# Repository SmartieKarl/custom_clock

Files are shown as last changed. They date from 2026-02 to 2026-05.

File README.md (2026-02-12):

# Custom Clock

This is an ESP32 based alarm clock with RFID functionality. The idea behind
this is that in order to turn off your alarm in the morning, you have to
physically get out of bed, grab your NFC card, and tap it on the reciever to
turn your alarm off. At that point you'll be more awake and have less of a
reason to go back to bed.

--------------------------------------------------------------------------

**[Please see LICENSE file for complete terms and conditions.](./LICENSE)**

--------------------------------------------------------------------------

# Setup

## Hardware

### Boards
- **Microcontroller:** ESP-WROOM-32 Dev Module ([Amazon](https://www.amazon.com/YEJMKJ-ESP-WROOM-32-Development-Dual-Mode-Microcontroller/dp/B0CDRKX814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)) ([AliExpress](https://www.aliexpress.us/item/3256809488479021.html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))
- **Display:** ST7789 240×320 SPI TFT ([Amazon](https://www.amazon.com/XIITIA-Display-Screen-240%C3%97320-Arduino/dp/B0D5HCDNY5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)) ([AliExpress](https://www.aliexpress.us/item/3256806903354055.html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))
- **RTC:** DS3231 ([Amazon](https://www.amazon.com/CANADUINO%C2%AE-DS3231-Module-Interface-Battery/dp/B07BCPRH6F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)) ([AliExpress](https://www.aliexpress.us/item/3256806957282138.html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))
- **Audio:** DFPlayer Mini ([Amazon](https://www.amazon.com/DFPlayer-A-Mini-MP3-Player/dp/B089D5NLW1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)) ([AliExpress](https://www.aliexpress.us/item/3256808368233947.html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))
- **NFC Functions:** RFID-RC522 ([Amazon](https://www.amazon.com/HiLetgo-RFID-Kit-Arduino-Raspberry/dp/B01CSTW0IA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)) ([AliExpress](https://www.aliexpress.us/item/3256806642614131.html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))

### Misc hardware
- a 2" speaker with two jumper wires. I used [this one](https://www.aliexpress.us/item/3256809273226082.html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,scm-url:1007.40050.354490.0,pvid:ea5149e1-a9d5-4bd2-9c6d-d897df53609c,tpp_buckets:668%232846%238109%231935&pdp_ext_f=%7B%22order%22%3A%22272%22%2C%22eval%22%3A%221%22%2C%22sceneId%22%3A%2230050%22%2C%22fromPage%22%3A%22recommend%22%7D&pdp_npi=6%40dis%21USD%2111.22%210.99%21%21%2177.01%216.78%21%402101df0e17709188654595016e0e1b%2112000049170771831%21rec%21US%21%21ABXZ%211%210%21n_tag%3A-29910%3Bd%3Af98f678%3Bm03_new_user%3A-29895%3BpisId%3A5000000197847434&utparam-url=scene%3ApcDetailTopMoreOtherSeller%7Cquery_from%3A%7Cx_object_id%3A1005009459540834%7C_p_origin_prod%3A), they come in sets of 2.
- a 1x2 header (for speaker) [here](https://www.aliexpress.us/item/3256803424019097.html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)
- 4 tactile buttons (like [these]())
- a 1x8 header (Optional, but recommended for RFID scanner range to be adequate) [here](https://www.aliexpress.us/item/3256803424019097.html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)
- 14-pin ribbon cable [here](https://www.aliexpress.us/item/3256805224133202.html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) 
- 2 2x7 IDC connectors [here](https://www.digikey.com/en/products/detail/cw-industries/CWR-130-14-0000/9899)
- a 2x7 dip socket (optional, but recommended if you want a way to disconnect the boards) [here](https://www.newark.com/multicomp-pro/spc15496/dip-socket-14-position-through/dp/82K7787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|pcrid||plid||kword||match|e|slid||product|82K7787|pgrid|1231453304461926|ptaid|pla-4580565455222458|&msclkid=5e18dbcbb6c91ab8dd9ab2458683c106)
- a microsd card for DFPlayer (max 32gb)
- a photoresistor
- a 1kΩ resistor, 2.2kΩ resistor, and 4.7kΩ resistor
- a 10μF capacitor and a 0.1μF capacitor
- a usb-c cable (only needed if you want to use electricity)

**Make sure all hardware you get matches the hardware on the boards in the photos at the bottom of this file**

## Pin Connections

### ST7789 Display
| TFT Pin | ESP32 Pin |
|---|---|
| CS | GPIO15 |
| RST | GPIO4 |
| DC | GPIO2 |
| MOSI | GPIO23 |
| SCLK | GPIO18 |
| LED | GPIO26 |

### DS3231 RTC (I²C)
| RTC Pin | ESP32 Pin |
|---|---|
| SDA | GPIO21 |
| SCL | GPIO22 |

### DFPlayer Mini (UART)
| DFPlayer | ESP32 Pin |
|---|---|
| TX | GPIO16 |
| RX | GPIO17 |

### RFID-RC522 (SPI)
| RFID Pin | ESP32 Pin |
|---|---|
| SDA/SS | GPIO5 |
| SCK | GPIO18 |
| MOSI | GPIO23 |
| MISO | GPIO19 |
| GND | GND |
| RST | GPIO25 |
| 3.3V | 3.3V |

## Other wiring

**Buttons**
There are four simple tactile buttons in use, they all use ESP32's
internal pull-up resistors:
- Button 1 (screen top left): GPIO14 -> button1 -> GND 
- Button 2 (screen top right): GPIO27 -> button2 -> GND
- Button 3 (screen bottom left): GPIO33 -> button3 -> GND
- Button 4 (screen bottom right): GPIO32 -> button4 -> GND

**DFPlayer mini voltage divider**
- So the DFPlayer's TX pin doesn't send 5v signals back to GPIO16 (bad)
- TX -> 1kΩ resistor --> GPIO16
                      |
                      -> 2.2kΩ resistor -> GND

**Photoresistor Circuit:**
- For auto-brightness functions
- 3.3v -> photoresistor -> GPIO34
                        |
                        -> 4.7kΩ resistor -> GND

### Power Supply
- **ESP32 Module:** 5v DC (regulated to 3.3v on-board)
- **TFT Display:** 3.3V (from ESP32)
- **DS3231 RTC:** 3.3V  (from ESP32)
- **DFPlayer Mini:** 5V (from ESP32)
- **RFID-RC522:** 3.3v (from ESP32)

## Software
Software is designed to work with **PlatformIO IDE** on **VSCode**.
Make sure they're installed for this to work correctly!

# Assembly

## Materials
You will need:
- All listed hardware above
- Access to a 3d printer and PCB mill (there are online services)
- Soldering iron
- 2 9mm long 5mm screws
- 2 5mm nuts for screws

## Printing & Milling
- Included in this repo is a [clock_parts](./clock_parts) folder. It contains the
    - gerber files (Already formatted for PCB milling)
    - stl files (for 3d printing of the clock shell)

- 3d print both shell pieces and 2 copies of the board spacer piece. The display piece **must** be printed clear for the
photoresistor to do it's thing.

- Mill the boards (must be electroplated and double-sided).

- Solder everything to boards (like pictures below)

- Place nuts in the shell (in the suspiciously nut-shaped divots) You might need to use pliers to press them in there.
If you're desperate, you can get them hot with a soldering iron to melt them in.

- Slide main board into the main shell (so the usb port is lined up with the back)

- Push display board into the front display piece, lining up the photoresistor with the rectangle cut out on the inside.

- plug the speaker into the main board, and the display board into the main board.

- Close up the shell and screw the screws in.

- Assembled!

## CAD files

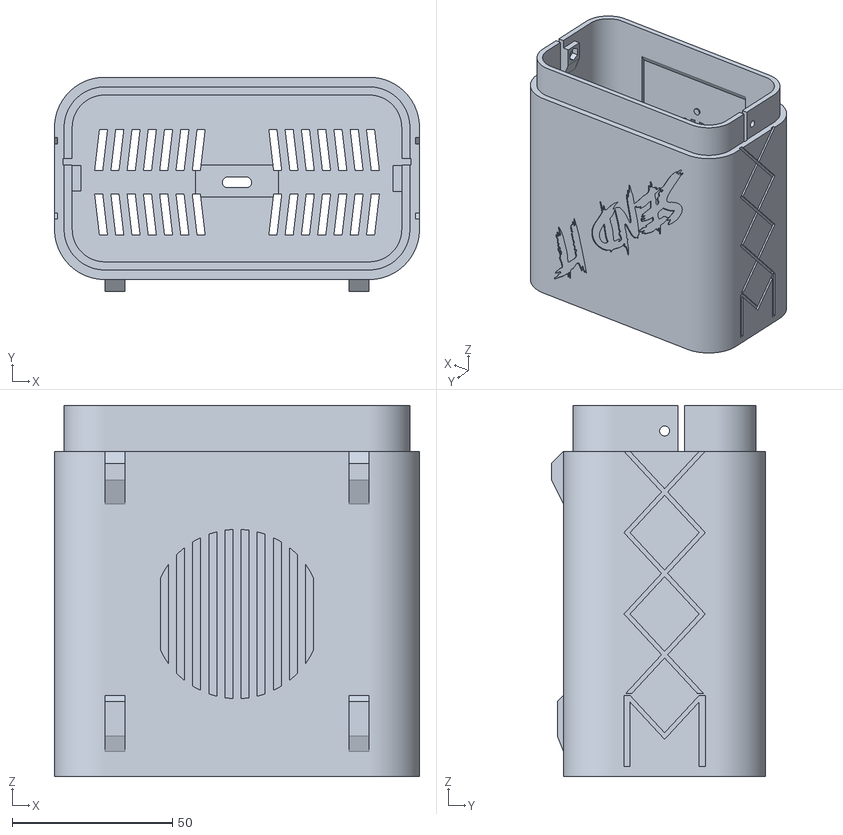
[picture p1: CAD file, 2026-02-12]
clock_parts/stl/clock_main_shell.stl
113.9 x 67.0 x 116.0

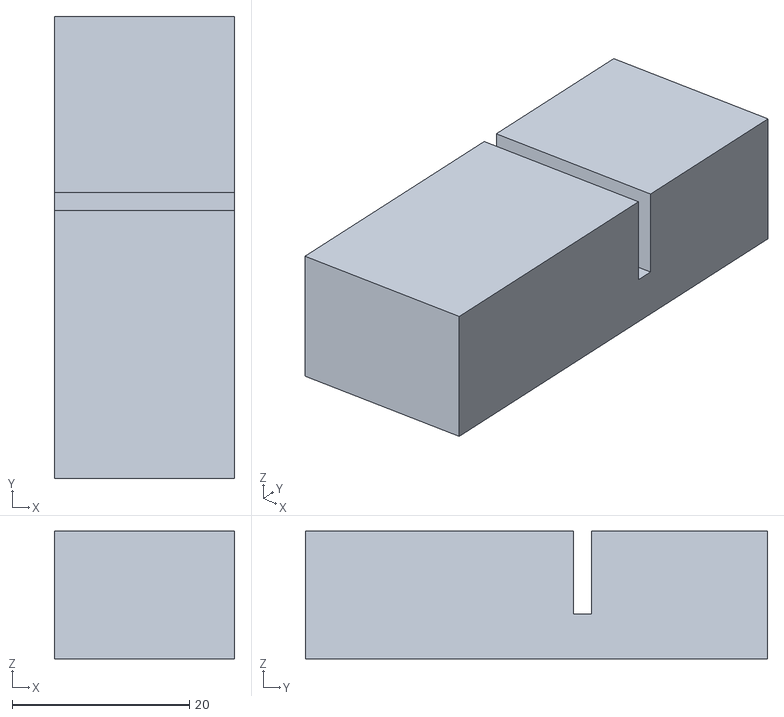
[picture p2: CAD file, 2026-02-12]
clock_parts/stl/clock_board_spacer.stl
20.3 x 52.1 x 14.4

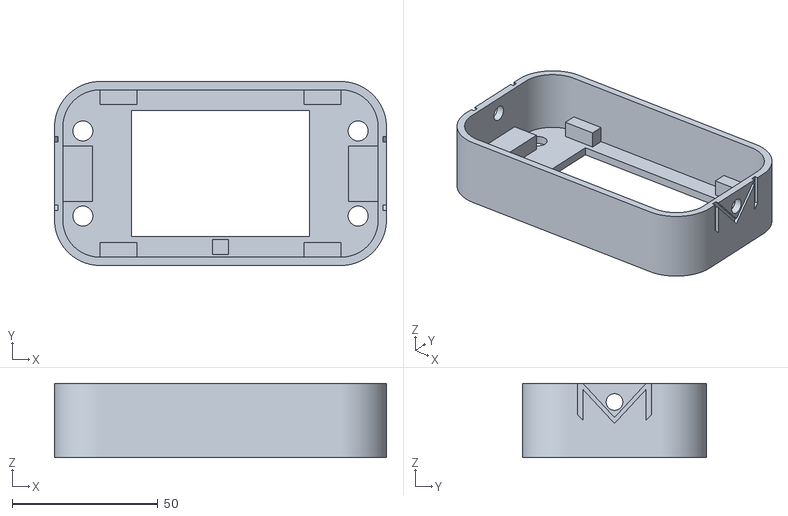
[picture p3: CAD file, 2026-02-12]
clock_parts/stl/clock_shell_front.stl
113.9 x 63.1 x 25.4

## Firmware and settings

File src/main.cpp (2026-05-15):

#include "AlarmSystem.h"
#include "AppController.h"
#include "BrightnessController.h"
#include "Buttons.h"
#include "CommandInterface.h"
#include "Config.h"
#include "Log.h"
#include "NetworkManager.h"
#include "RFIDHandler.h"
#include "Timekeeper.h"
#include "UI.h"
#include <DFRobotDFPlayerMini.h> // DFPlayer Mini core library
#include <HardwareSerial.h>      // Serial comms for DFPlayer Mini
#include <MFRC522.h>             // RFID core library
#include <RTClib.h>              // DS3231 RTC core library
#include <TFT_eSPI.h>            // ST7789 TFT core library
#include <esp_task_wdt.h>        // For freeRTOS task implementation

//==========
// TODO: Change singletons into universal objects to remove the need for object injection
//==========
// Hardware objects
DFRobotDFPlayerMini player;
HardwareSerial mySoftwareSerial(1); // UART1 for ESP32 (DFPlayer)
MFRC522 rfid(Pins::RFID_CS_PIN, Pins::RFID_RST_PIN);
RTC_DS3231 rtc;
TFT_eSPI tft = TFT_eSPI();

// Logic objects
Buttons btn(Pins::BUTTON_1_PIN, Pins::BUTTON_2_PIN, Pins::BUTTON_3_PIN, Pins::BUTTON_4_PIN); // TODO: add default pins into constructor
BrightnessController brightness;                                     // uses default pins from Config.h
Timekeeper timekeeper(rtc);
Log LOG(timekeeper);
NetworkManager networkManager(rtc);
RFIDHandler rfidHandler(rfid);
AlarmSystem alarmSystem(rtc, timekeeper, player);
UI ui(tft, btn, timekeeper, networkManager);
AppController appController(btn, rfidHandler, alarmSystem, ui, player);

CommandInterface commandInterface(player, timekeeper, ui, networkManager, alarmSystem);

//========== INITIALIZATION ==========
struct HardwareStatus
{
    bool rtcOK = true;
    bool rtcLostPower = false;
    bool playerOK = true;
    bool rfidOK = true;
};

void setupSys()
{
    // uSet.load(); // Load user settings from EEPROM (TODO: make this functional)

    // Watchdog
    esp_task_wdt_init(30, true);
    esp_task_wdt_add(NULL);
}

HardwareStatus setupBoard()
{
    HardwareStatus hs;

    //===== TFT init =====
    tft.init();
    tft.fillScreen(Colors::BACKGROUND_COLOR);

    //===== Brightness controller init =====
    // Must come after tft.init() so the PWM pin doesn't fight the TFT setup
    brightness.begin();

    //===== Buttons init =====
    btn.begin();  // creates Buttons mutex and sets pinMode
    btn.update(); // takes an initial reading so getState() is valid

    //===== RTC init =====
    if (!rtc.begin())
        hs.rtcOK = false;

    if (rtc.lostPower())
    {
        hs.rtcLostPower = true;
        rtc.adjust(DateTime(0, 1, 1, 0, 0, 0));
        rtc.setAlarm1(DateTime(0, 0, 0, 0, 0, 0), DS3231_A1_Hour);
        rtc.disableAlarm(1);
    }

    //===== Timekeeper init =====
    timekeeper.begin(); // creates Timekeeper mutex

    //===== DFPlayer init =====
    mySoftwareSerial.begin(9600, SERIAL_8N1, 16, 17); // RX=16, TX=17
    delay(1000);                                      // Wait for .begin() to succeed

    if (!player.begin(mySoftwareSerial))
        hs.playerOK = false;
    else
        player.volume(PLAYER_VOLUME);

    //===== RFID init =====
    SPI.begin();
    rfid.PCD_Init();

    byte version = rfid.PCD_ReadRegister(MFRC522::VersionReg);
    if (version == 0x00 || version == 0xFF)
        hs.rfidOK = false;

    //===== NetworkManager init =====
    networkManager.begin(); // creates mutex for network access

    return hs;
}

//========== HELPERS ==========
// Switch to help debug reason for crash/reset
const char *resetReasonToString(esp_reset_reason_t reason)
{
    switch (reason)
    {
    case ESP_RST_UNKNOWN:
        return "Unknown";

    case ESP_RST_POWERON:
        return "Power-on reset";

    case ESP_RST_EXT:
        return "External pin reset";

    case ESP_RST_SW:
        return "Software reset";

    case ESP_RST_PANIC:
        return "Exception/panic reset";

    case ESP_RST_INT_WDT:
        return "Interrupt watchdog reset";

    case ESP_RST_TASK_WDT:
        return "Task watchdog reset";

    case ESP_RST_WDT:
        return "Other watchdog reset";

    case ESP_RST_DEEPSLEEP:
        return "Wake from deep sleep";

    case ESP_RST_BROWNOUT:
        return "Brownout reset";

    case ESP_RST_SDIO:
        return "SDIO reset";

    default:
        return "Invalid/reset reason not recognized";
    }
}

void logResetReason()
{
    esp_reset_reason_t reason = esp_reset_reason();

    LOG.log(
        "\nREBOOT\n"
        "Reset code: %d\n"
        "Reason: %s",
        int(reason),
        resetReasonToString(reason));
}

void waitForUserContinue()
{
    unsigned long lastAction = millis();
    const unsigned long interval = 1000;

    tft.setTextColor(TFT_YELLOW);
    tft.print("Press any button to continue");

    while (!btn.getState().anyPressed())
    {
        unsigned long now = millis();
        if (now - lastAction >= interval)
        {
            tft.print(".");
            lastAction = now;
        }
        btn.update();
        delay(10);
    }
    tft.setTextColor(Colors::TEXT_COLOR);
}

// FreeRTOS tasks funciton definitions
void timeSyncTask(void *);
void weatherTask(void *);
void blynkTask(void *);

//==================== ENTRY POINT FOR PROGRAM ====================
void setup()
{
    Serial.begin(9600);

    setupSys();
    configTzTime(TIME_ZONE, "pool.ntp.org", "time.nist.gov");

    HardwareStatus hs = setupBoard();

    LOG.begin();
    logResetReason();

    alarmSystem.begin();
    ui.begin();

    //========== Callback registration ==========
    alarmSystem.onAlarmEvent([&]()
                             { ui.updateAlarmDisplay(); });

    ui.setAlarmDataCallback([&]() -> UI::AlarmDisplayData
                            {
            AlarmTime a = alarmSystem.getAlarm();
            return { a.hour, a.minute, a.enabled, alarmSystem.isRinging() }; });

    rfidHandler.onRFIDEvent([&](const char *uid)
                            {
            if (alarmSystem.isRinging())
            {
                alarmSystem.dismissAlarm();
                ui.flashScreen(TFT_GREEN);
            } });

    // Display hardware notification if available
    if (!ui.displayStartupStatus(hs.rtcOK, hs.rtcLostPower, hs.playerOK, hs.rfidOK))
        waitForUserContinue();
    else
        delay(3000);

    xTaskCreatePinnedToCore(timeSyncTask, "TimeSyncTask", 4096, NULL, 1, NULL, 1);
    xTaskCreatePinnedToCore(weatherTask, "WeatherTask", 4096, NULL, 1, NULL, 1);
    xTaskCreatePinnedToCore(blynkTask, "BlynkTask", 16384, NULL, 1, NULL, 1);

    ui.setState(State::Clock);
}

void loop()
{
    timekeeper.update();
    btn.update();

    rfidHandler.poll();

    alarmSystem.run();
    ui.run();

    appController.handleIn();

    brightness.updateAmbient();

    commandInterface.handleSerialIn();

    esp_task_wdt_reset();
    delay(10);
}

//==================== FreeRTOS Tasks ====================
// #define BLYNK_DEBUG
// #define BLYNK_PRINT Serial
#include <BlynkSimpleEsp32.h>

// Blynk callback functions here

// Command-response virtual pin
BLYNK_WRITE(V0)
{
    Serial.println("BLYNK_WRITE: started");
    const char *rsp = commandInterface.handleBlynkIn(param.asStr());
    if (rsp[0] != '\0') // Will be '\0' if the read command had the signature clock prefix: [CLK]:
    {
        // Write and notify
        Blynk.virtualWrite(V0, rsp);
        Blynk.logEvent("clock_reply", rsp);
        Serial.printf("rsp <%s> written to pin V0.", rsp);
    }
}

// On blynk connect, flush log to log pin (V1)
BLYNK_CONNECTED()
{
    Serial.println("BLYNK_CONNECTED: started");
    Blynk.sendCmd(BLYNK_CMD_PING); // Outbound ping to prevent server-side idle timeout
    Blynk.syncVirtual(V0);         // Syncs last value from cmd stream for execution
    // Log flush
    char buf[LOG_ENTRY_SIZE];

    while (LOG.pop(buf))
    {
        // Write to V1 (log stream)
        Blynk.virtualWrite(V1, buf);
        Blynk.logEvent("clock_log", buf);
        vTaskDelay(500); // to avoid flooding Blynk
    }
}

void timeSyncTask(void *)
{

    while (true)
    {
        networkManager.syncRTCFromNTP();
        DateTime now = timekeeper.time();
        uint32_t secondsToMidnight = (23 - now.hour()) * 3600 +
                                     (59 - now.minute()) * 60 +
                                     (60 - now.second());

        vTaskDelay(pdMS_TO_TICKS(secondsToMidnight * 1000ULL));
    }
}

void weatherTask(void *)
{
    while (true)
    {
        if (networkManager.fetchWeather())
            ui.updateWeatherDisplay(networkManager.currentWeather);
        else
            LOG.log("weatherTask failed to fetch weather data.");

        DateTime now = timekeeper.time();
        uint32_t secondsToNext = 0;
        if (now.minute() < 30)
        {
            secondsToNext = (30 - now.minute()) * 60 - now.second();
        }
        else
        {
            secondsToNext = (60 - now.minute()) * 60 - now.second();
        }

        vTaskDelay(pdMS_TO_TICKS(secondsToNext * 1000ULL));
    }
}

void blynkTask(void *)
{
    esp_task_wdt_add(NULL); // Watchdog safety

    Serial.println("BlynkTask: started");
    constexpr int MAX_RETRIES = 5;
    constexpr unsigned long BURST_MS = 20000; // 20s
    Blynk.config(BLYNK_AUTH);

    while (true)
    {
        bool persistent = networkManager.isWiFiPersistent();

        // Connect to WiFi (retry connection if periodic)
        bool connected = false;
        int retries = persistent ? 1 : MAX_RETRIES;

        for (int i = 0; i < retries && !connected; i++)
        {
            Serial.println("BlynkTask: attempting to connect to WiFi");
            if (networkManager.startWiFiSession())
            {
                Serial.println("BlynkTask: WiFi connected successfully.");
                connected = true;
            }
            else if (!persistent)
            {
                Serial.printf("BlynkTask: WiFi failed. Retrying... (%d/%d)\n", i + 1, MAX_RETRIES);
            }
            esp_task_wdt_reset();
        }

        // If connected, establish Blynk connection
        if (connected)
        {
            Blynk.connect(10000);
            esp_task_wdt_reset();
            if (Blynk.connected())
            {
                // Run Blynk
                if (persistent)
                {
                    // Persistent mode: run continuously until persistence ends
                    while (networkManager.isWiFiPersistent())
                    {
                        Blynk.run();
                        esp_task_wdt_reset();
                        vTaskDelay(pdMS_TO_TICKS(10));
                    }
                    Serial.println("BlynkTask: Persistence ended, closing WiFi.");
                }
                else
                {
                    // Burst mode: run for 10 seconds then disconnect
                    unsigned long start = millis();
                    while (millis() - start < BURST_MS)
                    {
                        Blynk.run();
                        esp_task_wdt_reset();
                        vTaskDelay(pdMS_TO_TICKS(10));
                    }
                }
                Blynk.disconnect();
                networkManager.endWiFiSession();
                Serial.println("BlynkTask: WiFi session ended.");
            }
        }
        else
            LOG.log("Failed to connect to Blynk cloud.");

        // After disconnect / failed connect
        DateTime now = timekeeper.time();
        uint32_t secondsToNext = 0;
        if (now.minute() < 30)
        {
            secondsToNext = (30 - now.minute()) * 60 - now.second();
        }
        else
        {
            secondsToNext = (60 - now.minute()) * 60 - now.second();
        }

        for (uint32_t i = 0; i < secondsToNext; i++)
        {
            esp_task_wdt_reset();
            vTaskDelay(pdMS_TO_TICKS(1000)); // Check every second
            if (networkManager.isWiFiPersistent())
                break;
        }
    }
}

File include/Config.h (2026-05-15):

#pragma once
#include "Vault.h"
#include <stdint.h>
#include <utility>

// TODO: Make namespace-based for better grouping

// config.h
// Multi-file pins, settings, and constants defined here

// ========== HARDWARE CONFIGURATION ==========
// for DS3231 control register access (writing alarms)
#define DS3231_ADDRESS 0x68
#define DS3231_CONTROL 0x0E

namespace Pins
{
// RFID-RC522 module pins
constexpr uint8_t RFID_CS_PIN = 5;    // SDA/SS pin for RFID
constexpr uint8_t RFID_RST_PIN = 25;  // Reset pin for RFID
constexpr uint8_t RFID_MISO_PIN = 19; // MISO pin for RFID

// Control button pins
constexpr uint8_t BUTTON_1_PIN = 14; // top left
constexpr uint8_t BUTTON_2_PIN = 27; // top right
constexpr uint8_t BUTTON_3_PIN = 33; // bottom left
constexpr uint8_t BUTTON_4_PIN = 32; // bottom right

// TFT LED brightness control
constexpr uint8_t TFT_LED_PIN = 26;       // PWM pin for TFT backlight control
constexpr uint8_t PHOTORESISTOR_PIN = 34; // ADC pin for ambient light sensor

// For a list of all hardware pin connections refer to /README.md
} // namespace Pins

// ========== DISPLAY CONFIGURATION ==========
namespace Colors
{
// Systemwide default colors
constexpr uint16_t BACKGROUND_COLOR = 0x0000; // Black
constexpr uint16_t TEXT_COLOR = 0xFFFF;       // White
} // namespace Colors

/*
========== MicroSD Card Contents ==========
Root:
-- Buzzer --
0001: Three square tone 1000hz

-- Soft(er) wakeup songs --
0002: Never Gonna Give You Up - Rick Astley
0003: Fortunate Son - Creedence Clearwater Revival
0004: Mii Channel Theme But Horrendous
0005: Circle of Life - The Lion King
0006: Thneedville - The Lorax
0007: Coconut Mall but in 6/8 Time SIgnature
0008: Smooth Criminal but Every Other Beat is Missing
0009: The Coconut Song

-- Hard wakeup songs --
0010: GOOOOOOD MORNING VIETNAM
0011: BOTW Guardian Theme
0012: SCOTLAND FOREVER
*/

namespace Tracks
{
// Track type ranges (ex: normal songs is spanning track 2 to track 9)
constexpr std::pair<uint8_t, uint8_t> buzzers = {1, 1};
constexpr std::pair<uint8_t, uint8_t> normalSongs{2, 9};
constexpr std::pair<uint8_t, uint8_t> loudSongs{10, 12};
constexpr std::pair<uint8_t, uint8_t> allSongs{1, 12};

constexpr uint8_t totalTrackCount = 12;
} // namespace Tracks

//!!! Going higher than 25 risks speaker damage !!!
constexpr uint8_t PLAYER_VOLUME = 20; // min 0, max 30

// ---------- Non-volatile settings ----------
// can be changed during runtime and persist between power cycles.
// Includes two functions to load/save variables to/from flash

/*This comment box contains all sensitive info constants which have been ommited
from the repository. These constants still need to be filled in or the program
won't work. References are in vault.h. Stay safe online!
// ========== NETWORK CONSTANTS ==========
WiFi and Clock sync settings
constexpr const char *WIFI_SSID = "ssid";
constexpr const char *WIFI_PASS = "password";
constexpr const char *TIME_ZONE = "UTC0"; //In POSIX time zone format

// Weather API settings (API key from OpenWeatherMap)
constexpr const char *WEATHER_API_KEY = "API_key";
constexpr const char *WEATHER_CITY = "City,ST";
constexpr const char *WEATHER_COUNTRY = "US";


// ========== RFID CONSTANTS ==========
// Master NFC tag UID
constexpr const char *ALARM_CARD_UID = "UID_here";
*/

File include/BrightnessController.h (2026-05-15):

#pragma once
#include "Config.h"
#include <Arduino.h>

// BrightnessController.h
// Hardware controller that updates tft backlight pin voltage using ambient light level

namespace BrightnessConfig
{
// TFT brightness control settings
constexpr uint8_t BRIGHTNESS_MIN = 1;   // Minimum disp brightness
constexpr uint8_t BRIGHTNESS_MAX = 255; // Maximum disp brightness

// Photoresistor ambient light control
constexpr uint16_t LIGHT_SENSOR_MIN = 120;       // ADC reading for darkest environment
constexpr uint16_t LIGHT_SENSOR_MAX = 1200;      // ADC reading for bright environment
constexpr uint8_t LIGHT_HYSTERESIS = 50;         // Prevent brightness flickering
constexpr uint32_t LIGHT_UPDATE_INTERVAL = 5000; // Check light level every 5 seconds

// Brightness fade settings
constexpr uint8_t FADE_STEP_SIZE = 2;               // How much to change brightness per step (smaller = smoother)
constexpr uint32_t FADE_STEP_DELAY = 5;             // Milliseconds between fade steps (smaller = faster fade)
constexpr uint8_t BRIGHTNESS_CHANGE_THRESHOLD = 20; // Minimum change in brightness needed to trigger fade
                                                    // Current calibration for 4.7kΩ pulldown resistor - tuned for room lighting ~1100 = 90%+ brightness

// PWM channel and frequency settings
static const uint8_t PWM_CHANNEL = 0;       // PWM channel (0-15 available)
static const uint32_t PWM_FREQUENCY = 5000; // 5kHz PWM frequency
static const uint8_t PWM_RESOLUTION = 8;    // 8-bit resolution (0-255)

} // namespace BrightnessConfig

class BrightnessController
{
  public:
    BrightnessController(uint8_t pwmPin = Pins::TFT_LED_PIN,
                         uint8_t pwmChannel = BrightnessConfig::PWM_CHANNEL,
                         uint32_t pwmFreq = BrightnessConfig::PWM_FREQUENCY,
                         uint8_t pwmRes = BrightnessConfig::PWM_RESOLUTION,
                         uint8_t photoresistorPin = Pins::PHOTORESISTOR_PIN);

    void begin();

    void setBrightness(uint8_t level);
    void setTargetBrightness(uint8_t level);

    void updateFade();
    void updateAmbient();

    uint8_t getBrightness() const;
    uint8_t getTargetBrightness() const;
    bool isFading() const;

  private:
    uint16_t readLightSensor() const;
    uint8_t calculateAmbientBrightness();

  private:
    uint8_t _pwmPin;
    uint8_t _pwmChannel;
    uint32_t _pwmFreq;
    uint8_t _pwmRes;
    uint8_t _photoresistorPin;

    uint8_t _currentBrightness;
    uint8_t _targetBrightness;

    uint16_t _lastLightReading;
    unsigned long _lastFadeUpdate;
    unsigned long _lastAmbientUpdate;
};

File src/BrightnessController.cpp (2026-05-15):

#include "BrightnessController.h"

using namespace BrightnessConfig;
// Constructor
BrightnessController::BrightnessController(uint8_t pwmPin,
                                           uint8_t pwmChannel,
                                           uint32_t pwmFreq,
                                           uint8_t pwmRes,
                                           uint8_t photoresistorPin)
    : _pwmPin(pwmPin), _pwmChannel(pwmChannel),
      _pwmFreq(pwmFreq), _pwmRes(pwmRes),
      _photoresistorPin(photoresistorPin),
      _currentBrightness(BRIGHTNESS_MAX),
      _targetBrightness(BRIGHTNESS_MAX),
      _lastLightReading(0),
      _lastFadeUpdate(0),
      _lastAmbientUpdate(0)
{
}

void BrightnessController::begin()
{
    ledcSetup(_pwmChannel, _pwmFreq, _pwmRes);
    ledcAttachPin(_pwmPin, _pwmChannel);
    pinMode(_photoresistorPin, INPUT);

    setBrightness(BRIGHTNESS_MAX);
    _lastLightReading = readLightSensor();
}

void BrightnessController::setBrightness(uint8_t level)
{
    if (level < BRIGHTNESS_MIN && level > 0)
        level = BRIGHTNESS_MIN;

    _currentBrightness = level;
    _targetBrightness = level;
    ledcWrite(_pwmChannel, _currentBrightness);
}

void BrightnessController::setTargetBrightness(uint8_t level)
{
    if (level < BRIGHTNESS_MIN && level > 0)
        level = BRIGHTNESS_MIN;

    _targetBrightness = level;
}

void BrightnessController::updateFade()
{
    unsigned long now = millis();
    if (now - _lastFadeUpdate < FADE_STEP_DELAY)
        return;
    if (_currentBrightness == _targetBrightness)
        return;

    if (_currentBrightness < _targetBrightness)
    {
        uint8_t step = (uint8_t)std::min((int)FADE_STEP_SIZE, (int)(_targetBrightness - _currentBrightness));
        _currentBrightness += step;
    }
    else
    {
        uint8_t step = (uint8_t)std::min((int)FADE_STEP_SIZE, (int)(_currentBrightness - _targetBrightness));
        _currentBrightness -= step;
    }

    ledcWrite(_pwmChannel, _currentBrightness);
    _lastFadeUpdate = now;
}

uint16_t BrightnessController::readLightSensor() const
{
    return analogRead(_photoresistorPin);
}

uint8_t BrightnessController::calculateAmbientBrightness()
{
    uint16_t light = readLightSensor();

    if (abs((int)light - (int)_lastLightReading) < LIGHT_HYSTERESIS)
        light = _lastLightReading;
    else
        _lastLightReading = light;

    if (light < LIGHT_SENSOR_MIN)
        light = LIGHT_SENSOR_MIN;
    if (light > LIGHT_SENSOR_MAX)
        light = LIGHT_SENSOR_MAX;

    return map(light, LIGHT_SENSOR_MIN, LIGHT_SENSOR_MAX,
               BRIGHTNESS_MIN, BRIGHTNESS_MAX);
}

void BrightnessController::updateAmbient()
{
    unsigned long now = millis();

    updateFade();

    if (now - _lastAmbientUpdate < LIGHT_UPDATE_INTERVAL)
        return;

    uint8_t newTarget = calculateAmbientBrightness();
    if (abs((int)newTarget - (int)_targetBrightness) > BRIGHTNESS_CHANGE_THRESHOLD)
        setTargetBrightness(newTarget);

    _lastAmbientUpdate = now;
}

uint8_t BrightnessController::getBrightness() const { return _currentBrightness; }
uint8_t BrightnessController::getTargetBrightness() const { return _targetBrightness; }
bool BrightnessController::isFading() const { return _currentBrightness != _targetBrightness; }

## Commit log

2025-11-20 Updated files to correct version - files were outdated - found correct versions in local backup and restored state
    [User_Setup.h, alarm.cpp, main.cpp]
2025-11-20 Hardware functionality patch - fixed bugs that broke rtc & DFPlayer comms - cleaned up logic - fixed bug where initial display states did not draw
    [User_Setup.h, main.cpp]
2025-11-20 updated implementation of AlarmTime struct - AlarmTime struct object can be updated easier - AlarmTime struct object can be flashed to EEPROM, allowing runtime mods to survive power cycles
2025-11-21 Revised alarm storage location - Alarm times are stored locally in RTC - Added exception handling if RTC loses power/alarm settings
2026-01-07 Complete file restructure to emphasize seperation - Seperation of all hardware objects is implemented now - Only the dedicated driver file can interact with the hardware object directly
2026-02-12 Command Update - Added command interface - Supports commands from local (Serial) and remote (Blynk MQQT) sources - Added Blynk support, with passive and active connection modes - reorganized file str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
    [clock_board_spacer.stl, clock_main_shell.stl, clock_shell_front.stl]
2026-05-11 Major update: complete file overhaul - Code structure is now logic-centered instead of hardware-centered - Object-based organization to keep organization tight and updateable - Files are named differ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
    [AlarmSystem.cpp, BrightnessController.cpp, BrightnessController.h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]
2026-05-15 Bug fixes and command expansion - network should play nicer now - command system is expanded, with ways to customize alarm presets and access the full log system from the command line.
    [BrightnessController.cpp, BrightnessController.h, CommandInterface.cpp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]
